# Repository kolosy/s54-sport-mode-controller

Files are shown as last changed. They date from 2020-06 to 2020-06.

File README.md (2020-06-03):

# S54 Sport mode controller
This is a sport mode controller for the S54 Z3 M. It works by pulling a line to the DME to ground for 1 second, and then keeping track of state and turning on the dash light. This only works on the S54 engined Z3 M, as the functoinality exists in the DME but isn't broken out by default. You will need to add the dash light, and the missing pin housing to the DME connector to make this work.

The housing STLs were made with OnShape, and are available as CAD files here:
https://cad.onshape.com/documents/bd9cbe37f7debc0799cd37cb/w/cd3ee4e9e2b90868aebbf150/e/c24e36f81ab31e6954b87d38

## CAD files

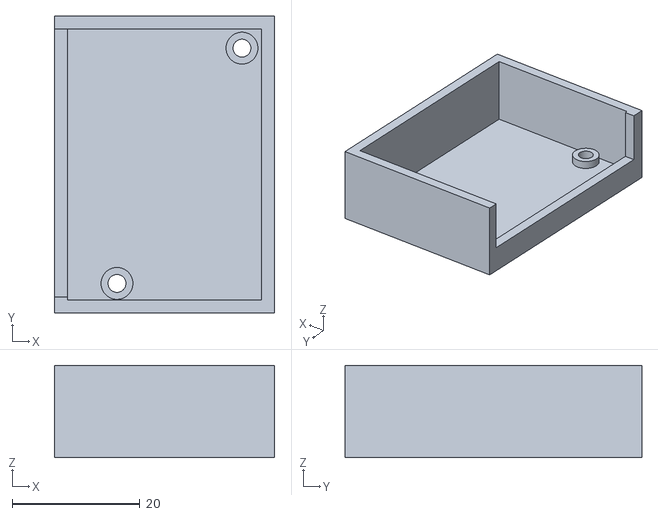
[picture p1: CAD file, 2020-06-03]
housing-bottom.stl
34.5 x 46.5 x 14.5

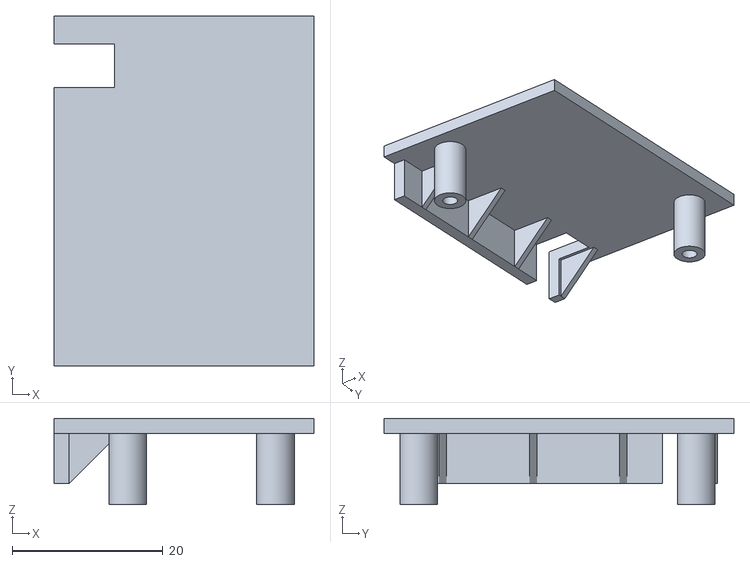
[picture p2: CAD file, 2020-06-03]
housing-top.stl
34.5 x 46.5 x 11.4

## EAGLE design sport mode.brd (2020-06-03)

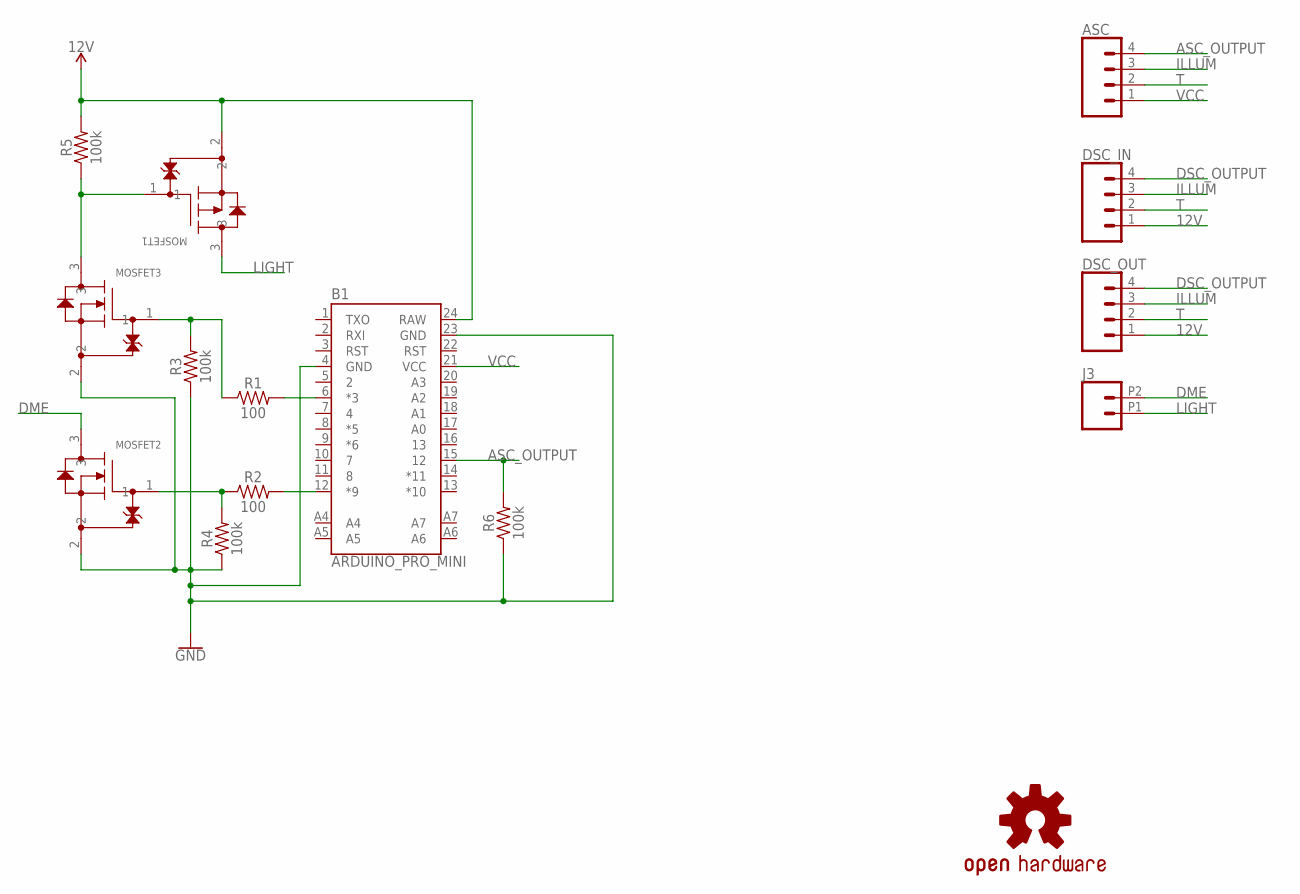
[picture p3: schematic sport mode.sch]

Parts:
ASC: CONN_04; 1X04
B1: ARDUINO_PRO_MINI
DSC_IN: CONN_04; 1X04
DSC_OUT: CONN_04; 1X04
J3: CONN_022.54MM_SCREWTERM; 1X02_2.54_SCREWTERM
LOGO1: OSHW-LOGOL-COPPER; OSHW-LOGO-L_COPPER
MOSFET1: SSM3J328R; SOT-23F
MOSFET2, MOSFET3: SSM3K329R; SOT-23F
R1, R2: 100; 0603
R3, R4, R5, R6: 100k; 0603

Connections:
12V: B1.24 (RAW), DSC_IN.1, DSC_OUT.1, MOSFET1.2, R5.2
ASC_OUTPUT: ASC.4, B1.15 (12), R6.2
DME: J3.P2 (2), MOSFET2.3
DSC_OUTPUT: DSC_IN.4, DSC_OUT.4
ILLUM: ASC.3, DSC_IN.3, DSC_OUT.3
LIGHT: J3.P1 (1), MOSFET1.3
unnamed: B1.12 (*9), R2.2
unnamed: B1.6 (*3), R1.2
unnamed: MOSFET2.1, R2.1, R4.2
unnamed: MOSFET3.1, R1.1, R3.2
unnamed: MOSFET1.1, MOSFET3.3, R5.1
T: ASC.2, B1.4 (GND), B1.23 (GND), DSC_IN.2, DSC_OUT.2, MOSFET2.2, MOSFET3.2, R3.1, R4.1, R6.1
VCC: ASC.1, B1.21 (VCC)

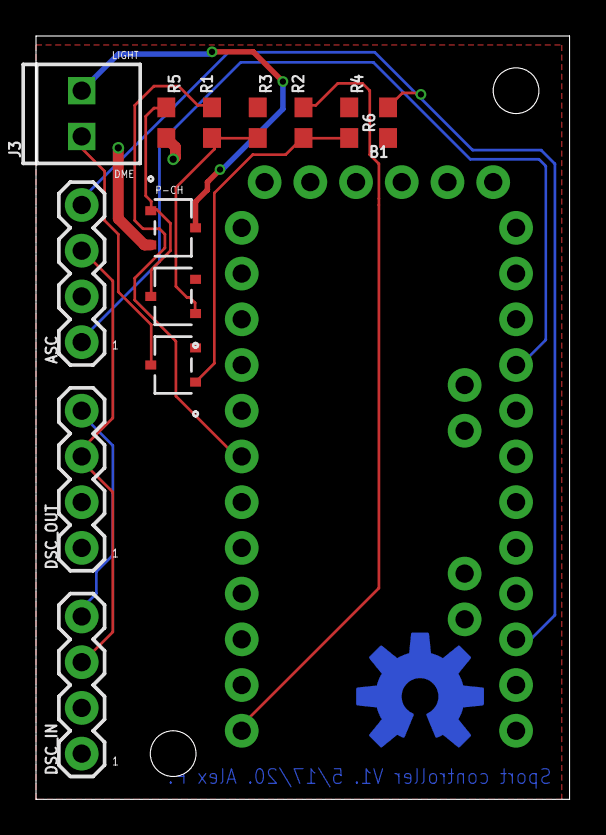
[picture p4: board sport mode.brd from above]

Board: 2 copper layers, 29.6 x 42.4 mm, 15 parts (1 on the bottom side), 13 nets.

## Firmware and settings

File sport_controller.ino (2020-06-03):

#define LIGHT 3
#define SIGNAL 9
#define SWITCH 12

long timeOfPress = 0;
bool on = false;

void setup() {
  // put your setup code here, to run once:
  pinMode(SWITCH, INPUT);
  pinMode(LIGHT, OUTPUT);
  pinMode(SIGNAL, OUTPUT);

  digitalWrite(LIGHT, LOW);
  digitalWrite(SIGNAL, LOW);

  Serial.begin(9600);
}

void loop() {
  // debounce
  if (millis() - timeOfPress < 1000)
    return;

  if (digitalRead(SWITCH) == HIGH) {
    Serial.println("Pressed");
    timeOfPress = millis();

    on = !on;

    // we manage the state of the light
    digitalWrite(LIGHT, on ? HIGH : LOW);

    Serial.print("Turning light ");
    Serial.println(on ? "on" : "off");

    // the signal pin is a toggle, so we just emulate one
    digitalWrite(SIGNAL, HIGH);
    delay(1000);
    digitalWrite(SIGNAL, LOW);
  }
}

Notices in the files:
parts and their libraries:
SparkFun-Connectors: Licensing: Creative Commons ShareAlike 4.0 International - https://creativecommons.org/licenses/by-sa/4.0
